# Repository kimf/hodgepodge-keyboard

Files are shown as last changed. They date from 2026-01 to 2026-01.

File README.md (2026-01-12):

# HodgePodge

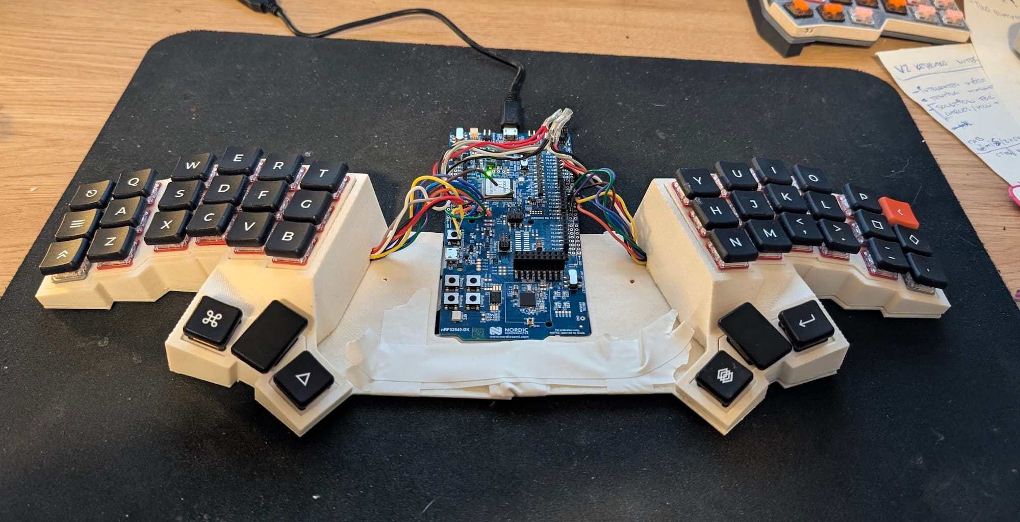
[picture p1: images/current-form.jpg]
Current Form


A keyboard, built using things I had lying around, for example a NRF52840-DK devcard, ec11 encoder, some weird display from AliExpress and a bunch of switches/diodes etc.
I also managed to get an old 3d printer (an ultimaker 2+) going with Klipper to print the parts.

- PS. It was hard to find good 2.85mm filament these days!p
- PS2. The screen is either broken or its a skill issue on my part, so will probably scrap that "tower" in the middle and go wireless split with a dongle instead
- PS3. Learning fusion as well so see the files in the 3d-files folder for what it is!

Was initially inspired by this beautiful keyboard: https://github.com/sevmeyer/chrumm-keyboard

And countless others of course, skeletyl, dactyl, cosmos, the corne I have been using for a year etc...

Wanted to experiment with some different placements for the thumb buttons and some more splay etc measured after my own fingers,
and also make the switchplate separately so I can keep experimenting without having to resolder, just build a new case or something where the plates fits, and move them there.

## Process notes

Started with testing things out on a cardboard with some old switches by just pressing them in.
Then designed the layout with <https://editor.keyboard-tools.xyz> - 
[My layout url](https://editor.keyboard-tools.xyz/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)

Used ai03 Plate Generator (ai03 Plate Generator) to generate a plate, that I imported in to Fusion and placed the switchholder with socketholder on each "square". duplicate with joints was a great revelation to learn here!

After that I did a lot of "lofting" to get the plate and the case somewhat functional. Printed prototypes, discarded every one and finally started soldering some diodes and wires to the back of the plate and connected them to the devcard

I also tried playing with the great tool Cosmos Keyboard Generator <https://ryanis.cool/cosmos> - here are those attempts:
- [First attempt](https://ryanis.cool/cosmos/beta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)
- [Second attempt](https://ryanis.cool/cosmos/beta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)

I also did a lot of exploration with different SCAD variants, generators etc. Contemplating using solderless versions etc.
But.. two goals with this projects were to get better at fusion and especially getting over my fear of soldering.

PS there are some in progress images in the images folder

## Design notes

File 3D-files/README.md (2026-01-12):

# HodgePodge STL and STEP

For now this is a dumping ground for  prototypes, and should be considered as such.

Tolerances are definitively something that needs to be worked on.
So far I've printed everything on a super old Ultimkaker 2+ with Klipper and used exclusevily PLA from Add:North and 0.6 nozzle, not caring too much about quality

The Plates I consider fairly simple and will probably update to be a bit sturdier and have some more room at the edges for soldering diodes and such, but ive used them two times as is.
The rest are still WIP.

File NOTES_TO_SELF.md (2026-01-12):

# Notes to self for now

## Flashing the nrf card

nrfutil device program --firmware hodgepodge-nrf52840dk_nrf52840-zmk.bin --traits jlink --options chip_erase_mode=ERASE_ALL

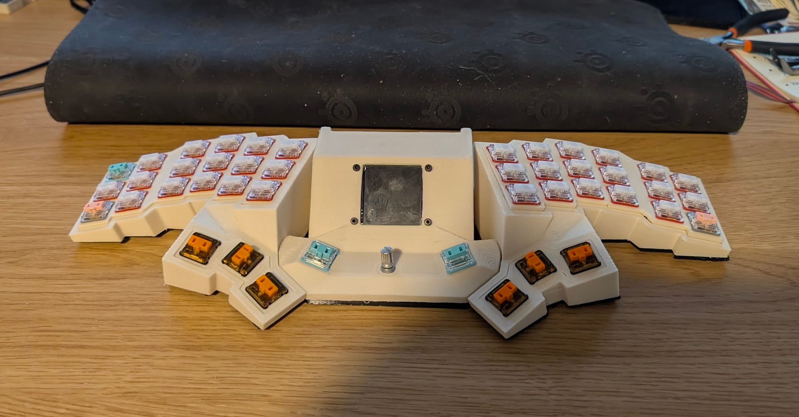
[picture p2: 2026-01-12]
images/prototype smaller housing.jpg

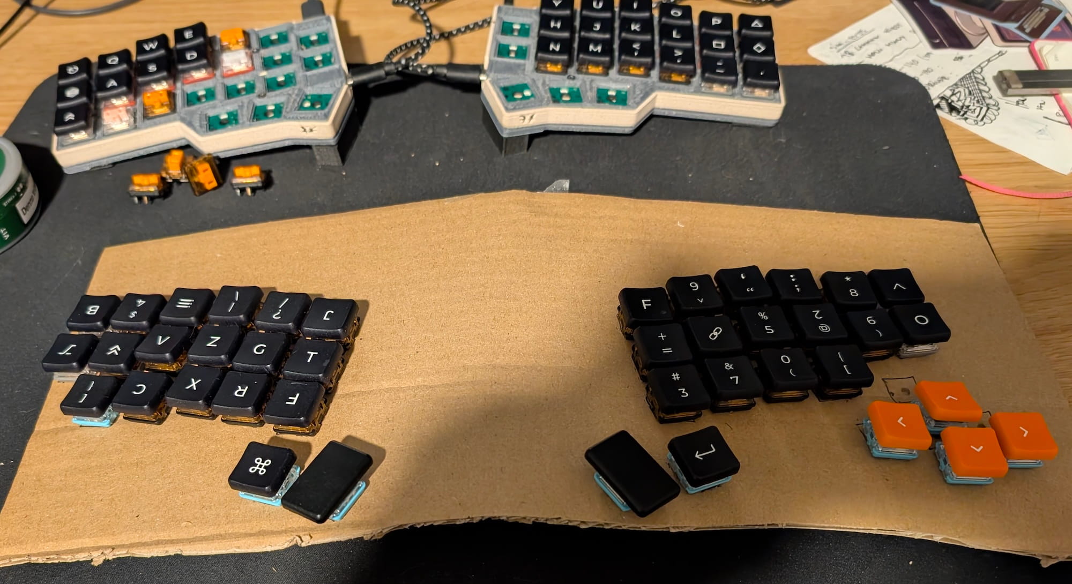
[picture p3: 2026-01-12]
images/cardboard-prototyping.jpg

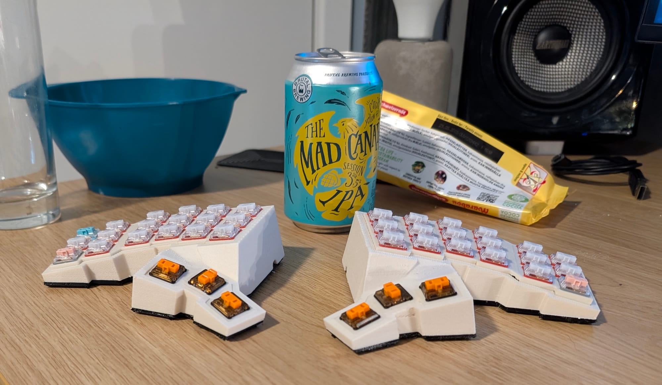
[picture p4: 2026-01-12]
images/prototype-split.jpg

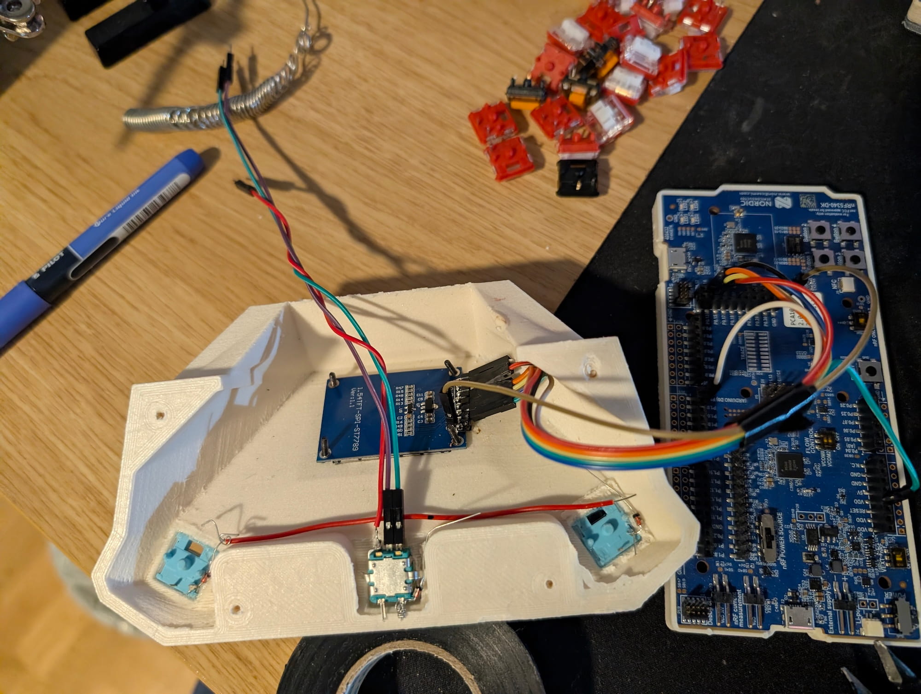
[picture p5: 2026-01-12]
images/mounting screen and ec11.jpg

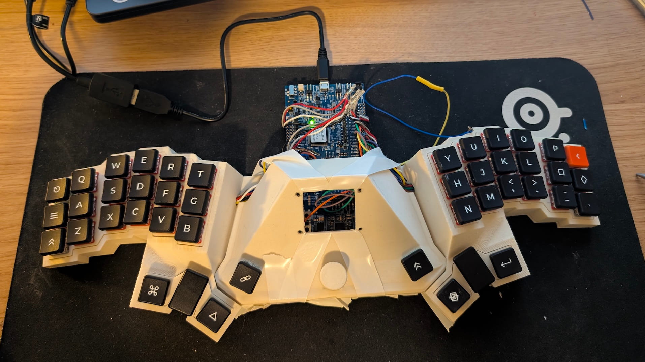
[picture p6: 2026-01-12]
images/prototype larger housng.jpg

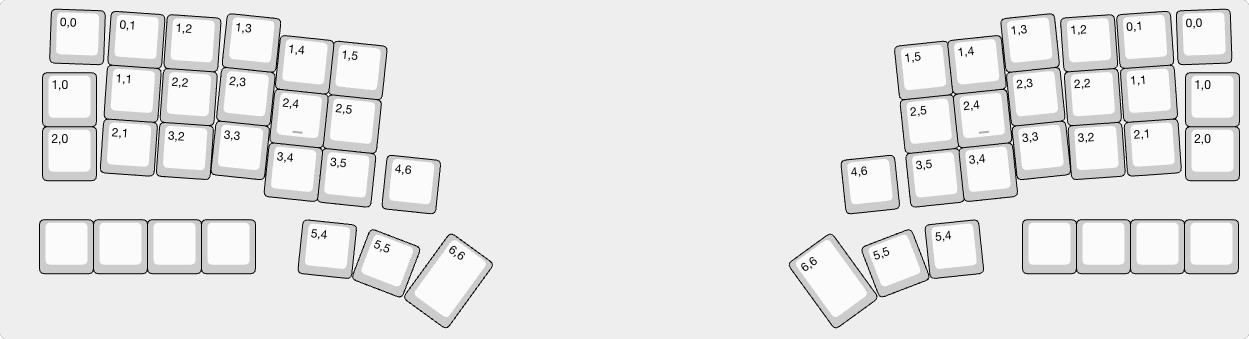
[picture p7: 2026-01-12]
Keylayout/2025-12-07/2025-12-07-HodgePodge.png

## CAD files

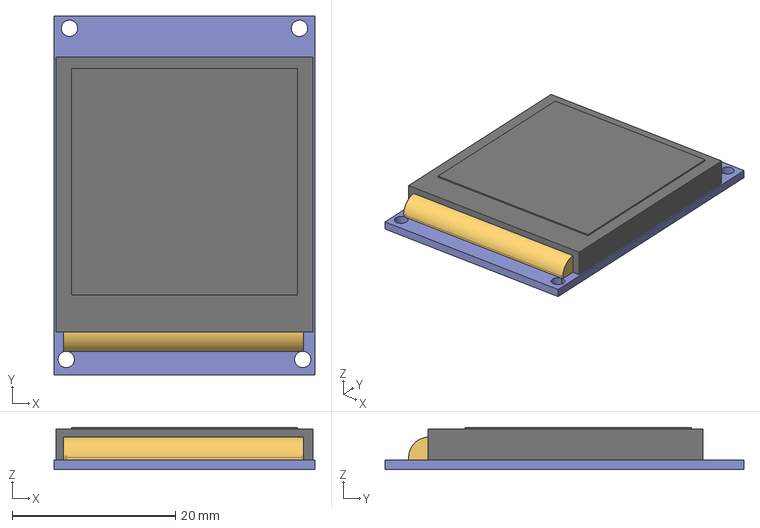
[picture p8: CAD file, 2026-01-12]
3D-files/STEP/_PARTS/240x240-Display.step
32.0 x 44.0 x 5.20 mm

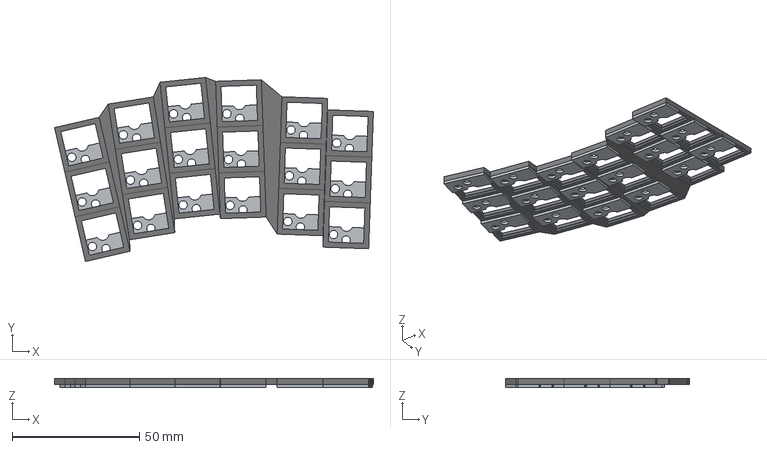
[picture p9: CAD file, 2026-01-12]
3D-files/STEP/RightPlate.step
125.4 x 72.3 x 3.35 mm

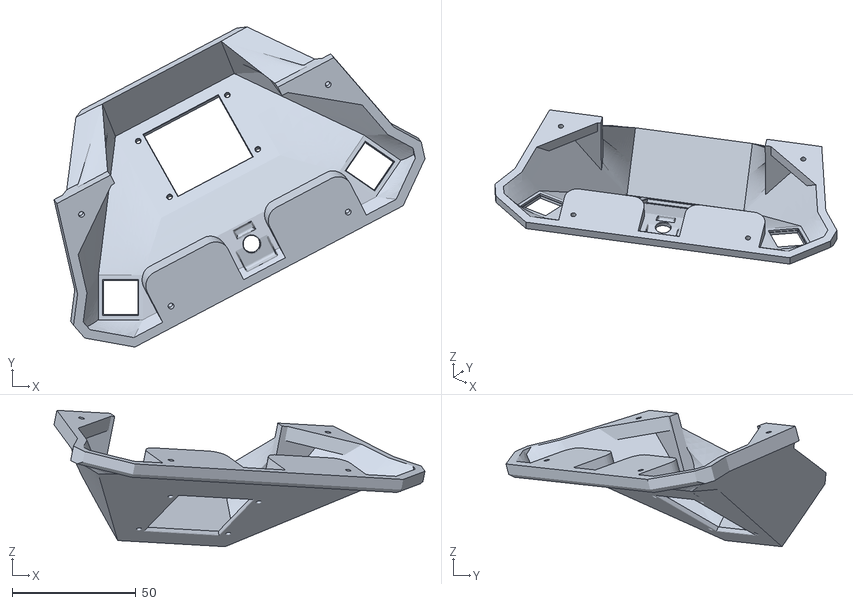
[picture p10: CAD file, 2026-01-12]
3D-files/STL/Housing.stl
150.0 x 129.4 x 55.1

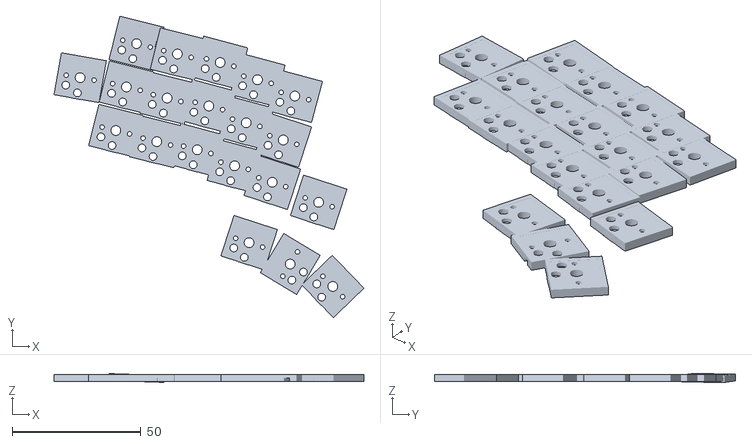
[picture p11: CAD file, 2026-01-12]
3D-files/testing-layout-and-choc-holders/HodgePodge-ChocPlate-Left.stl
120.3 x 117.0 x 3.44

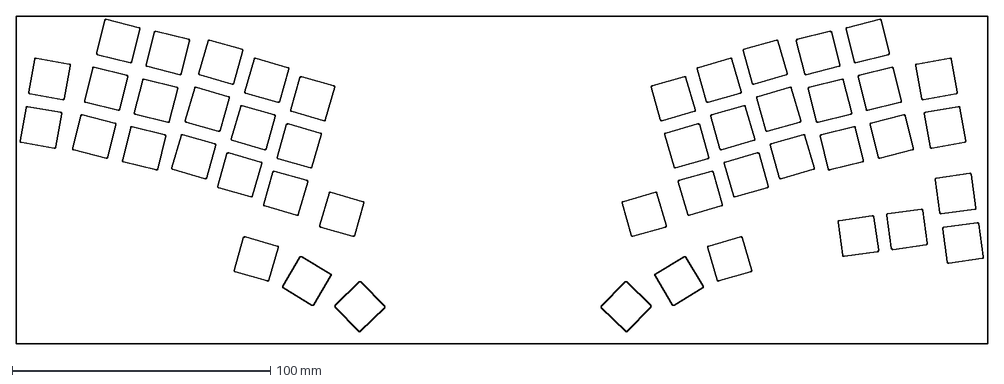
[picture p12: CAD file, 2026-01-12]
Keylayout/2025-12-05/plate-2025-12-05T16_11_48.764Z.dxf
376.2 x 126.7 mm

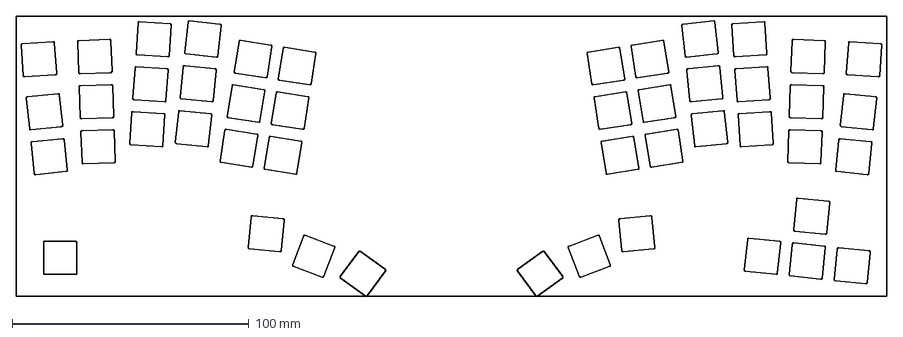
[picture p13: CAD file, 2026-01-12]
Keylayout/2025-12-19/plate-2025-12-19T23_50_06.461Z.dxf
367.4 x 118.3 mm

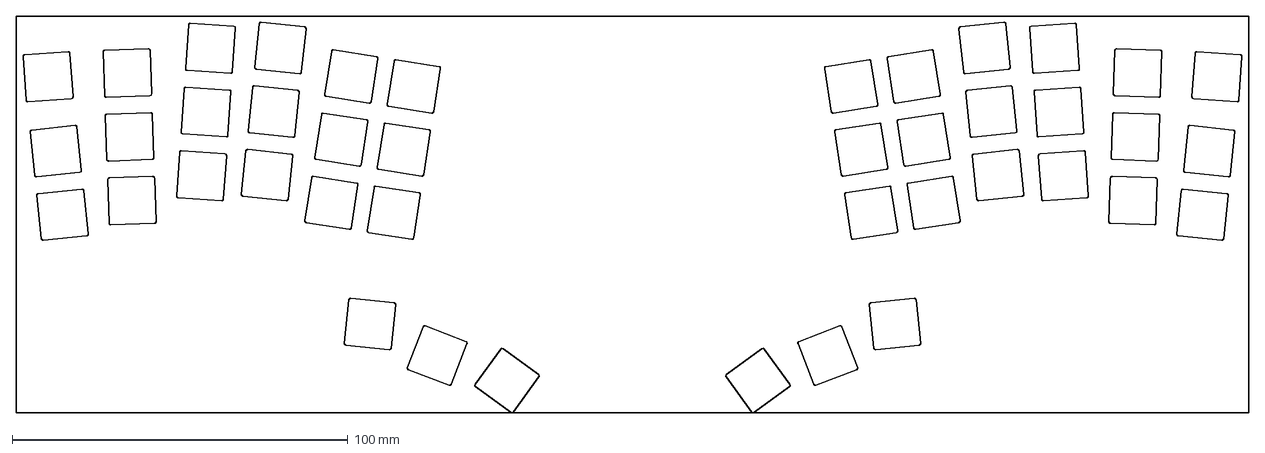
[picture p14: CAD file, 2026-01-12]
Keylayout/2025-12-29/plate-2025-12-29T11_55_51.143Z.dxf
367.4 x 118.3 mm

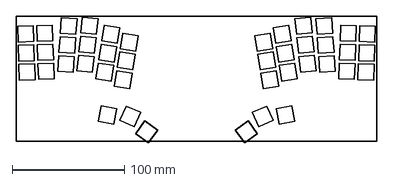
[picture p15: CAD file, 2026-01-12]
Keylayout/2025-12-31/plate-2025-12-31T13_04_32.578Z.dxf
321.4 x 112.7 mm

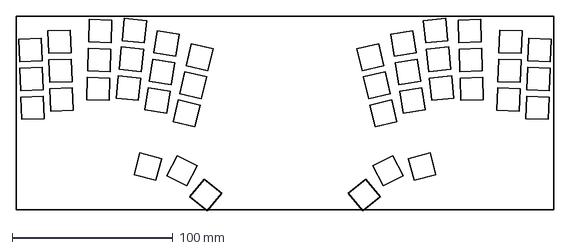
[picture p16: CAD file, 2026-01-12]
Keylayout/2026-01-03/plate-2026-01-03T15_07_53.795Z.dxf
334.9 x 121.3 mm

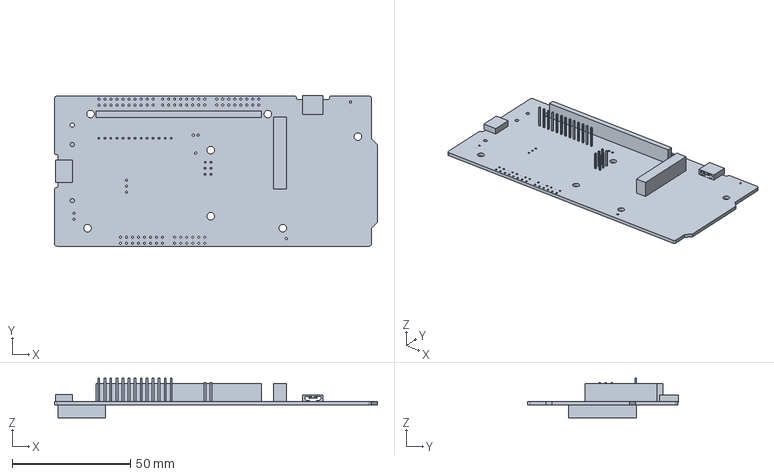
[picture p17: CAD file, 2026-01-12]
3D-files/STEP/_PARTS/nRF5340DK-Boxy.step
136.5 x 63.6 x 16.7 mm

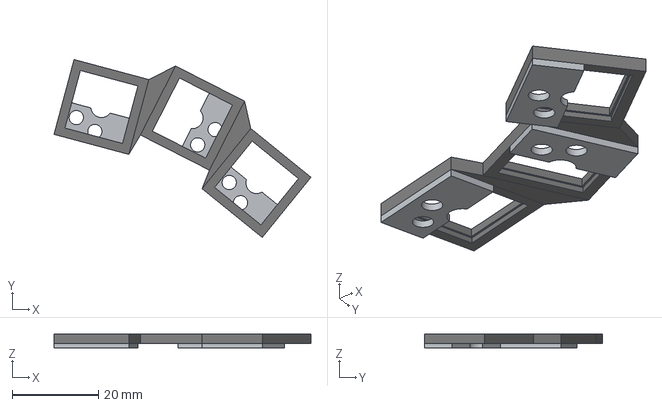
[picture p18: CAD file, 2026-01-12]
3D-files/STEP/LeftThumbPlate.step
59.7 x 41.3 x 3.35 mm

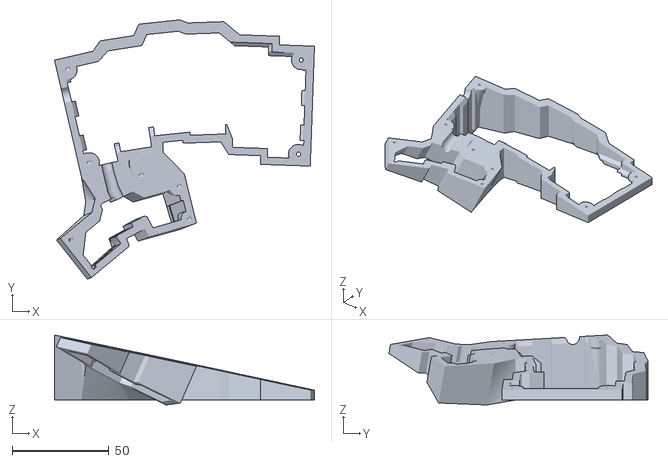
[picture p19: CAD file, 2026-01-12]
3D-files/STL/LeftWalls.stl
134.3 x 133.9 x 36.2

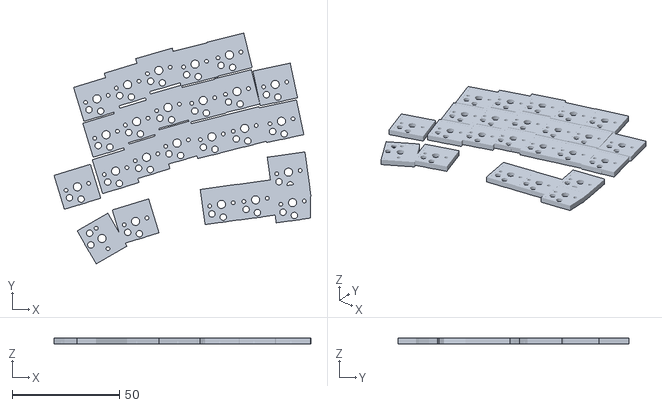
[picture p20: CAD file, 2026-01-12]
3D-files/testing-layout-and-choc-holders/HodgePodge-ChocPlate-Right.stl
119.6 x 107.4 x 2.70

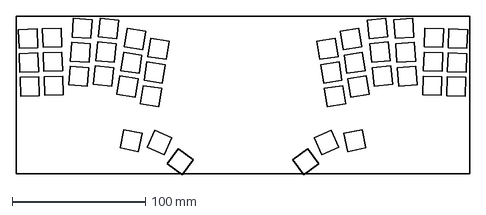
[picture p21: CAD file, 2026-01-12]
Keylayout/2025-12-31/plate-2025-12-31T13_27_50.016Z.dxf
340.3 x 118.8 mm

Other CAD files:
3D-files/STEP/_PARTS/EC11-boxy.step
3D-files/STEP/RightThumbPlate.step
3D-files/STL/RightBottomPlate.stl
3D-files/testing-layout-and-choc-holders/HodgePodge-BasePlate-Left.stl
3D-files/STEP/LeftPlate.step
3D-files/STL/LeftBottomPlate.stl
3D-files/STL/LeftPlate.stl
3D-files/STL/LeftThumbPlate.stl
3D-files/STL/RightPlate.stl
3D-files/STL/RightThumbPlate.stl
3D-files/STL/RightWalls.stl
3D-files/STL/_OLDER_PROTOTYPES/_DISCARDED_MIDSECTION/bottom.stl
3D-files/STL/_OLDER_PROTOTYPES/_DISCARDED_MIDSECTION/housing.stl
3D-files/STL/_OLDER_PROTOTYPES/_DISCARDED_SPLIT_BOTTOMPLATES/LeftBottomPlate-IF-SPLIT.stl
3D-files/STL/_OLDER_PROTOTYPES/_DISCARDED_SPLIT_BOTTOMPLATES/RightBottomPlate-IF-SPLIT.stl
3D-files/STL/_OLDER_PROTOTYPES/take-1--printed-bad-fit-for-sockets/LeftBottomPlate.stl
3D-files/STL/_OLDER_PROTOTYPES/take-1--printed-bad-fit-for-sockets/LeftTopPlate.stl
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

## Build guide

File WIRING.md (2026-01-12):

# WIRING

## Cable Colors

### Rows

Row 0 - Black
Row 1 - Red
Row 2 - White
Row 3 - Gray

### Right half

Col 12   - Purple
Col 11   - Green
Col 10   - Brown
Col 9    - Yellow
Col 8    - Blue
Col 7    - Orange

### Left half

Col 1   - Purple
Col 2   - Green
Col 3   - Brown
Col 4   - Yellow
Col 5   - Blue
Col 6   - Orange

---;

## Temporary wiring to NRF52845, will probably be replaced with nice nanos.

Row 0 - Black - P1.12
Row 1 - Red   - P1.13
Row 2 - White - P1.14
Row 3 - Gray  - P1.15

### Right half pins

Col 12 - Purple - P1.03
Col 11 - Green  - P1.04
Col 10 - Brown  - P1.05
Col 9  - Yellow - P1.06
Col 8  - Blue   - P1.07
Col 7  - Orange - P1.08

### Left half pins

Col 1 - Purple - P0.03
Col 2 - Green  - P0.04
Col 3 - Brown  - P0.28
Col 4 - Yellow - P0.29
Col 5 - Blue   - P0.30
Col 6 - Orange - P0.31

### Macro pins

Row - Green - P1.10

Left - Orange - Col 12 - P1.03
Middle - Blue/yellow - Col 11 - P1.04
Right - Purple - Col 10 - P1.05

---;

## Display, Pin, Cable color

VCC,VDD (3.3V)            - Green
GND,GND                   - Brown
SCL (Clock),P0.27         - Blue
SDA (MOSI),P0.26          - Yellow
RES (Reset),P0.05         - Orange
DC (Data/Cmd),P0.06       - Red
CS (Chip Select),P0.08    - Black
BLK (Backlight),P0.07     - White

___;

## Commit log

2026-01-06 Update nrf5340dk configuration for display and encoder
2026-01-06 try another board
2026-01-07 testing moving encoder pins
2026-01-08 moved to boards folder
2026-01-10 testing to move RC(3,5) to its own pin
2026-01-12 Added some docs and images
    [240x240-Display.step, 240x240-Display.stl, EC11-boxy.step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]
2026-01-12 Enhance README with design and process details
    Updated README with additional details about thumb button placements, switchplate design, and layout generation tools used in the project.
